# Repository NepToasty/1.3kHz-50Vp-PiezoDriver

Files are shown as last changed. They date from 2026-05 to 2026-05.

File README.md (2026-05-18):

# 1.3kHz-50Vp-PiezoDriver
1.3kHz 50Vp PiezoDriver

PiezoPCB1
PiezoPCB2

## Safety Warning and Disclaimer

This project is an experimental open-source hardware design. It can generate and/or expose voltages greater than 30 VAC, including potentially hazardous voltages. Contact with energized parts may cause electric shock, burns, equipment damage, fire, injury, or death.

This design is provided for informational, educational, and experimental use only. It is not a certified product, not safety-approved, and not intended for use in medical, life-support, safety-critical, automotive, industrial control, or other applications where failure could cause injury, death, property damage, or regulatory non-compliance.

Anyone who builds, modifies, tests, powers, or uses this design does so entirely at their own risk. The user is solely responsible for verifying the design, selecting suitable components, following applicable electrical safety practices, using appropriate insulation, fusing, enclosures, creepage/clearance distances, personal protective equipment, and complying with all applicable laws, standards, and regulations.

The authors, contributors, and copyright holders make no warranties or guarantees of any kind, express or implied, including but not limited to correctness, safety, fitness for a particular purpose, reliability, regulatory compliance, or suitability for any application.

To the fullest extent permitted by law, the authors, contributors, and copyright holders shall not be liable for any claim, damage, injury, loss, expense, or other liability arising from or related to the use, misuse, construction, modification, testing, or distribution of this project or any device based on it.

Do not build or operate this project unless you understand the risks of working with hazardous voltages.

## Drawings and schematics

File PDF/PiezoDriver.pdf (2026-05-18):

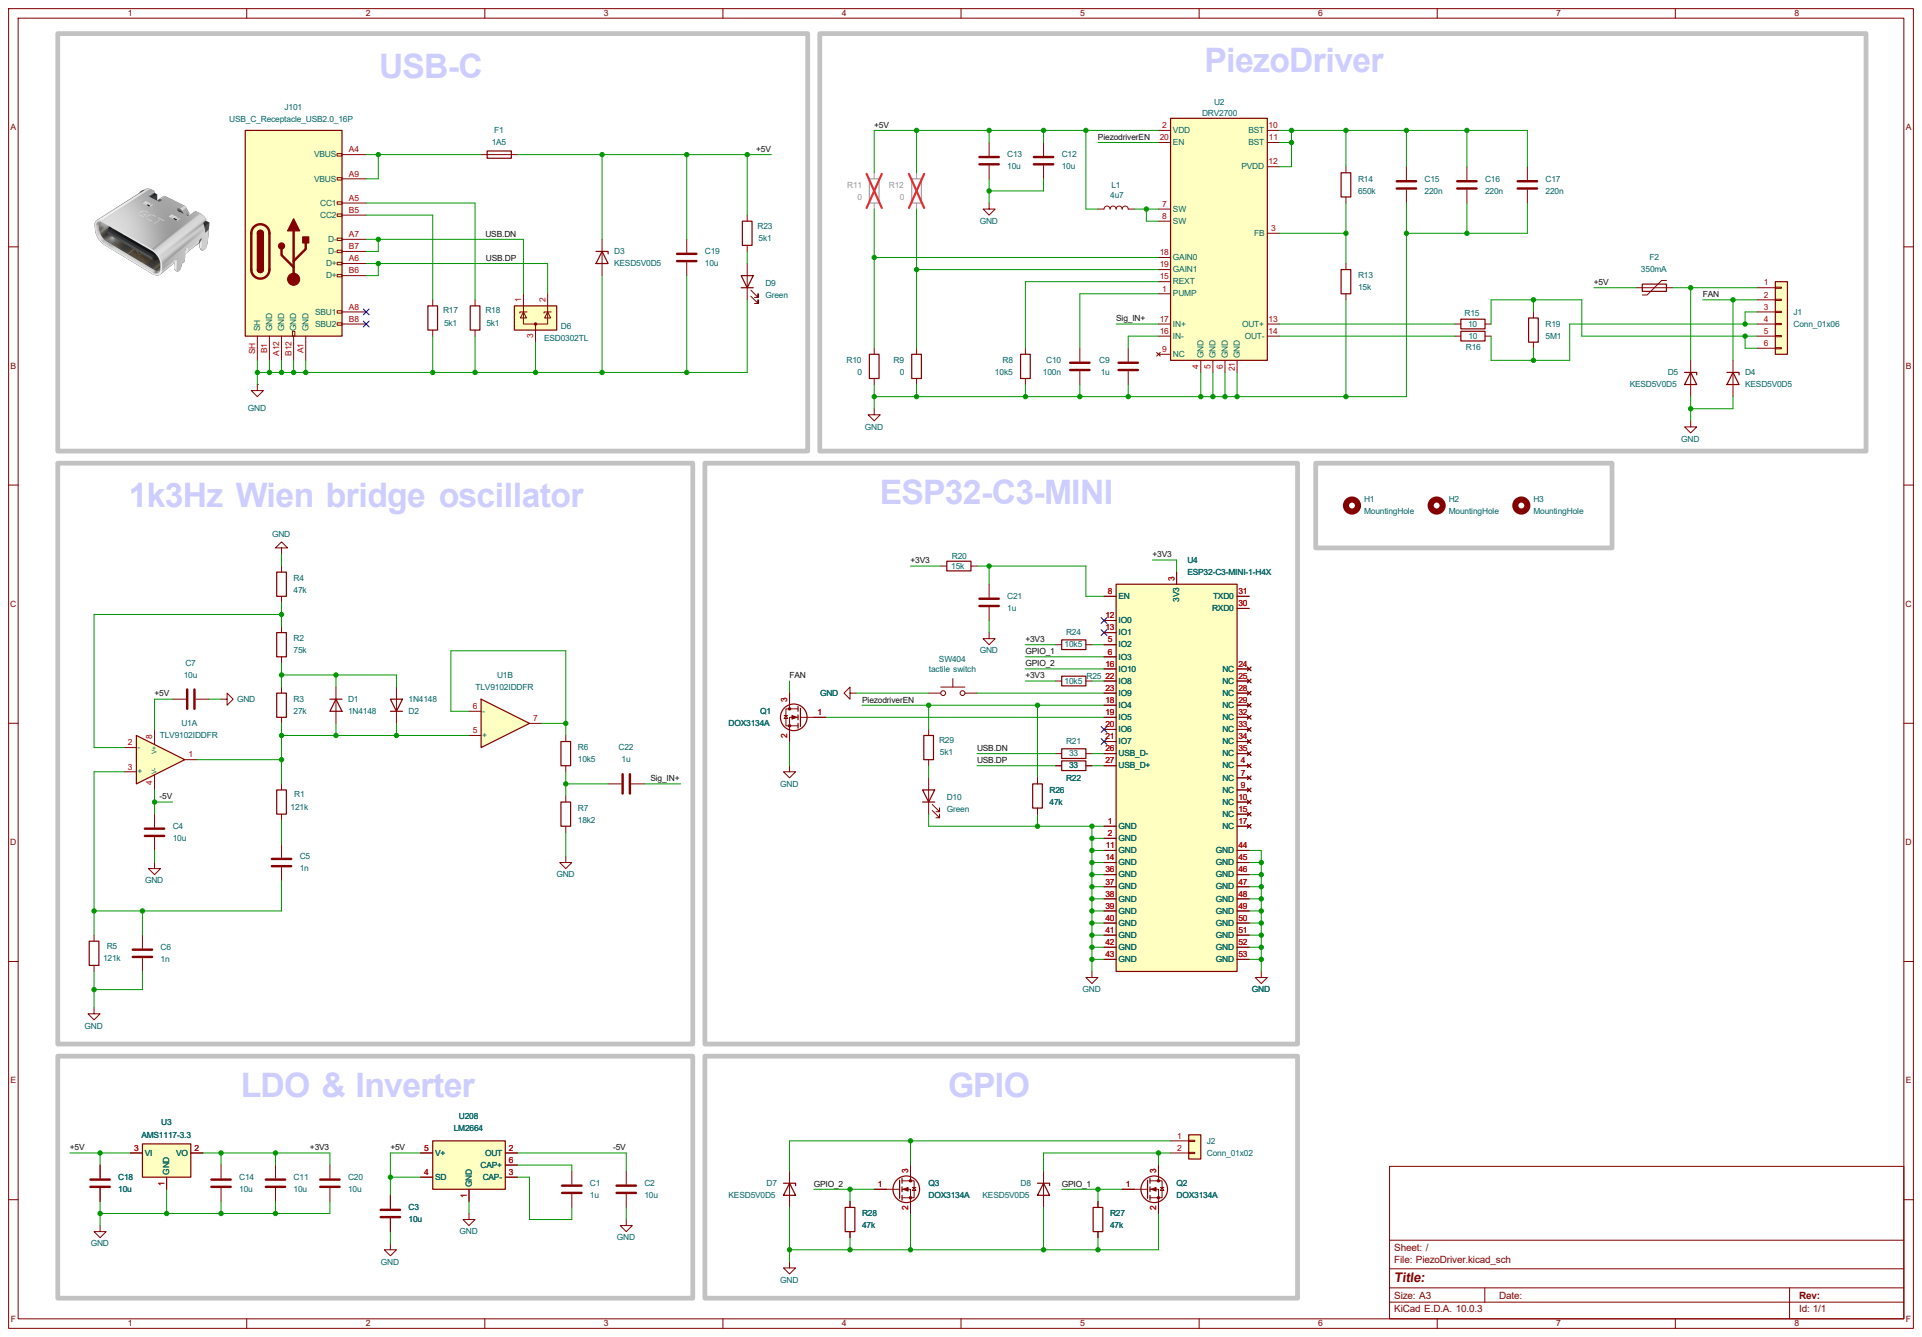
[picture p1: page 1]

6 SW 7 SW 8 NC 9 BST 10 BST 11 PVDD 12 OUT+ 13 OUT- 14 REXT 15

1 OUT 2 CAP- 3 SD 4 V+ 5 CAP+ 6 U208
LM2664 GND

1 OUT 2 CAP- 3 SD 4 V+ 5 CAP+ 6

Id: 1/1 Title: File: PiezoDriver.kicad_sch Sheet: /

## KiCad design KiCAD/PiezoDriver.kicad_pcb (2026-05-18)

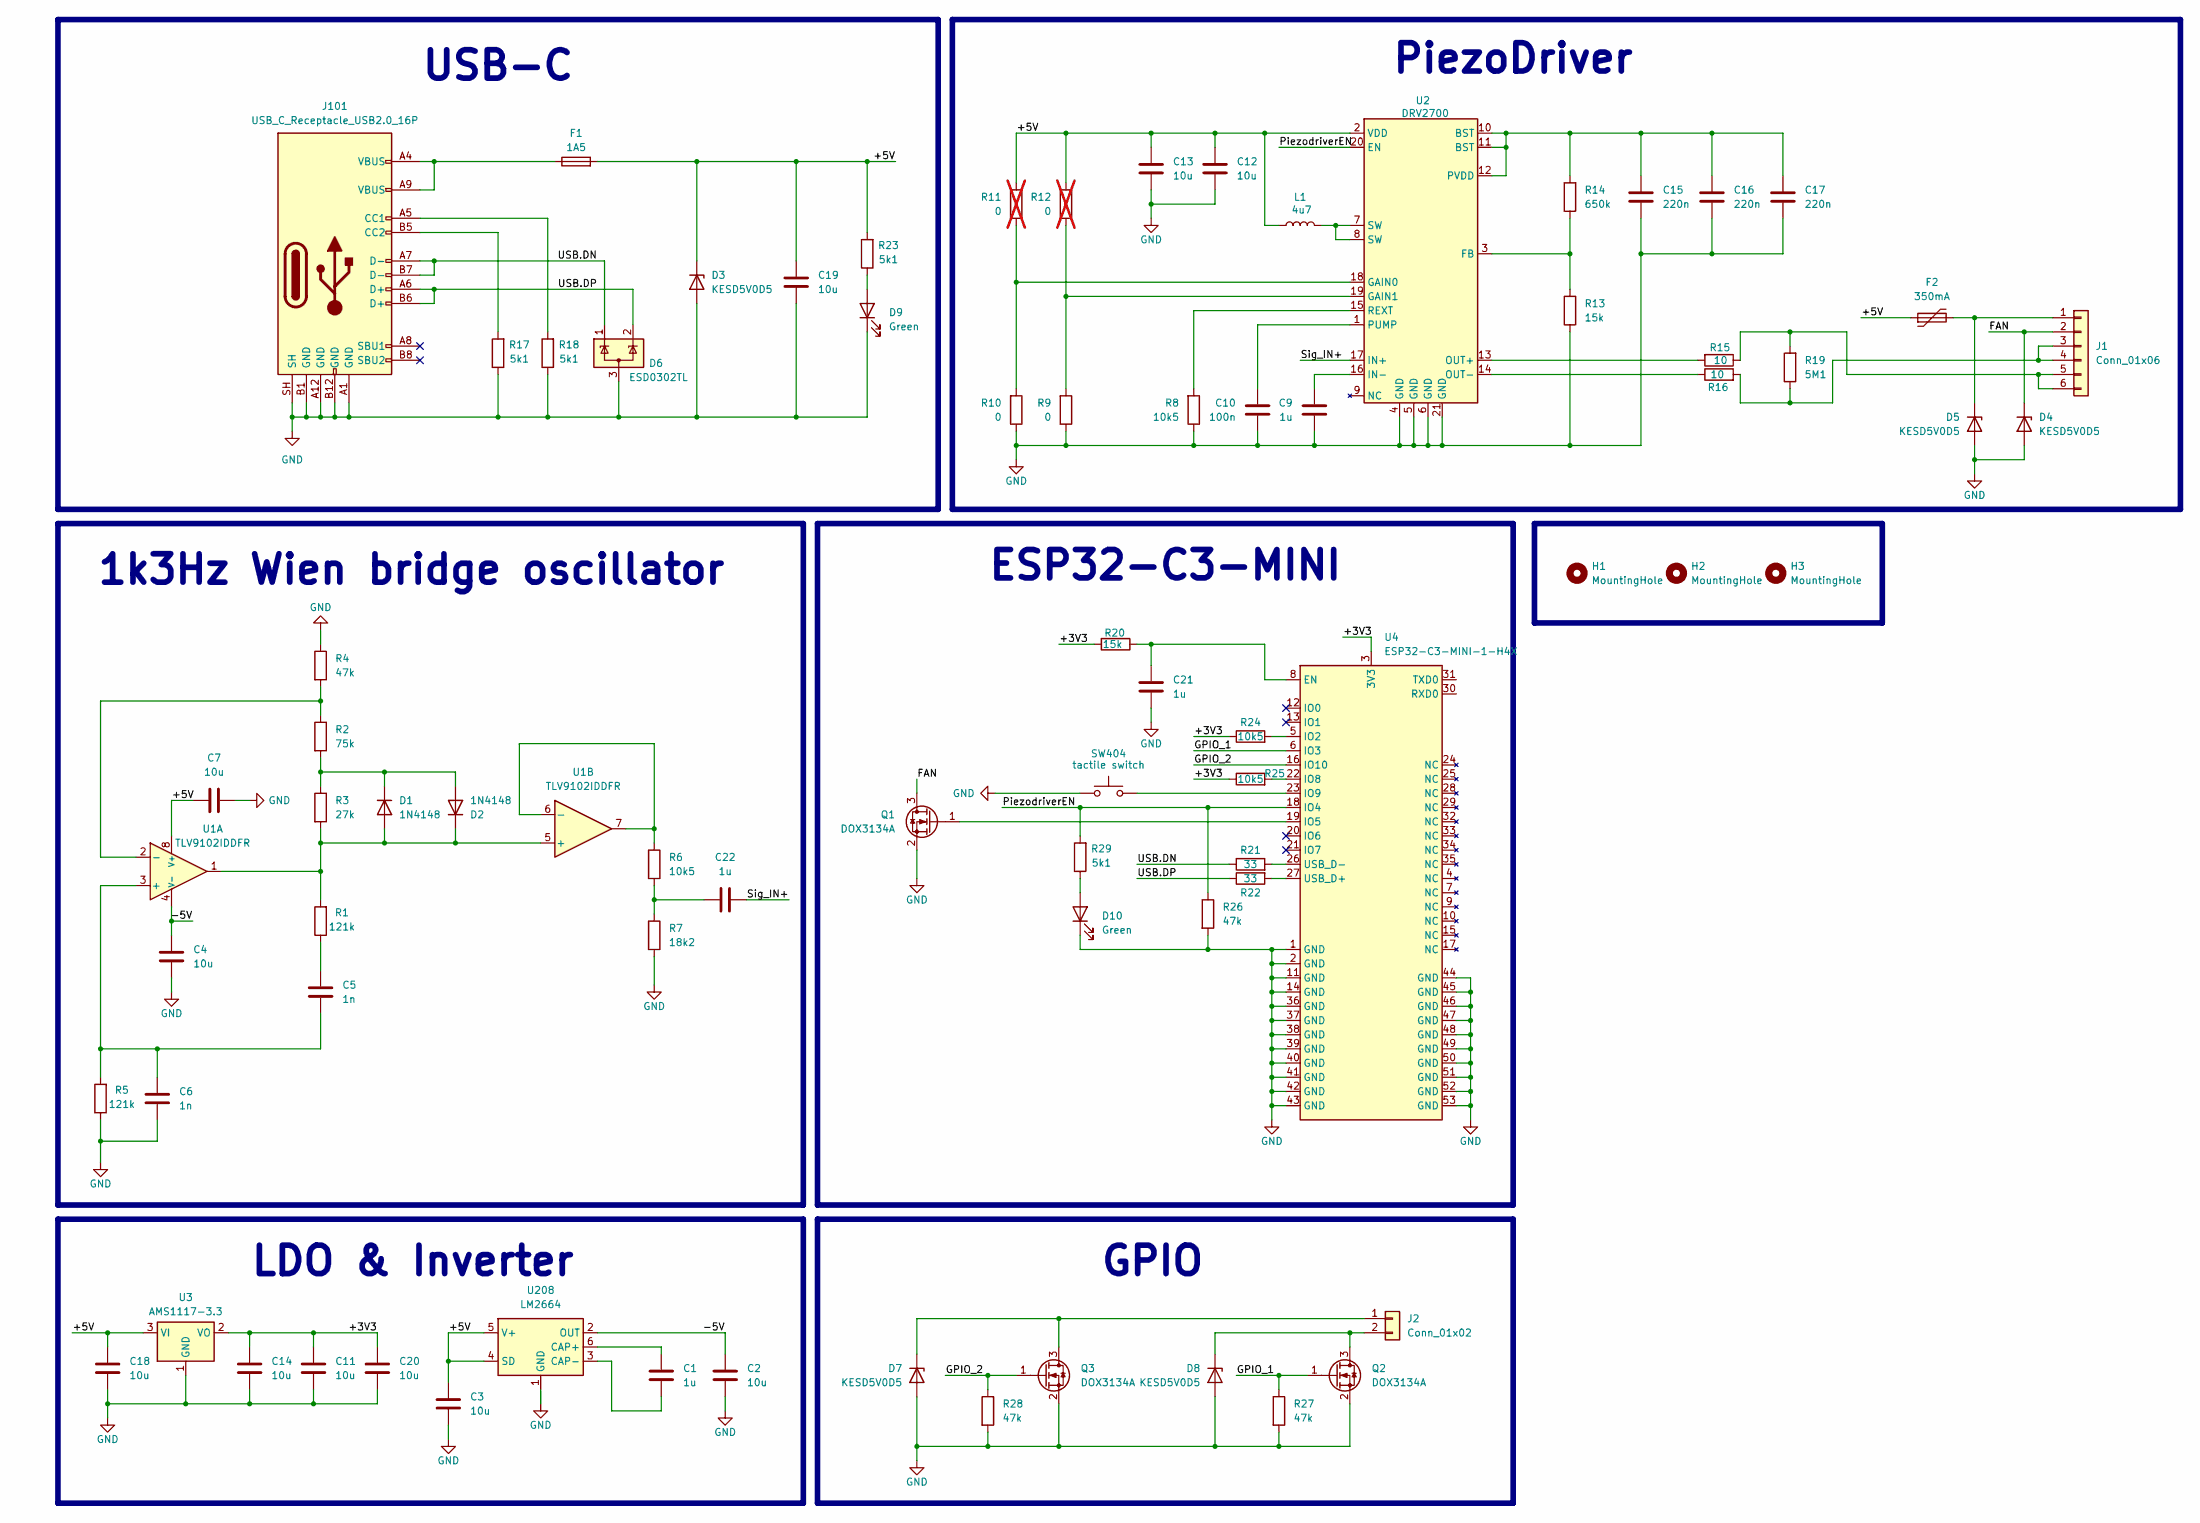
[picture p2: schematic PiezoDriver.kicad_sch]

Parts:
C1, C9, C21, C22: 1u; C_0603_1608Metric; LCSC C5199872
C2, C3, C4, C7, C11, C12, C13, C14, C18, C19, C20: 10u; C_0603_1608Metric; LCSC C6119842
C5, C6: 1n; C_0402_1005Metric; LCSC C76947
C10: 100n; C_0402_1005Metric; LCSC C77020
C15, C16, C17: 220n; C_1206_3216Metric; LCSC C880778
D1, D2: 1N4148; D_SOD-323; LCSC C60580
D3, D4, D5, D7, D8: KESD5V0D5; D_SOD-523; LCSC C2892517
D6: ESD0302TL; SOT-23; LCSC C502588
D9: Green; LED_0603_1608Metric; LCSC C52675989
D10: Green; LED_0603_1608Metric; LCSC C51933298
F1: 1A5; Fuse_0603_1608Metric; LCSC C52988544
F2: 350mA; Fuse_0603_1608Metric; LCSC C7501938
H1, H2, H3: MountingHole; MountingHole_2.2mm_M2_DIN965
J1: Conn_01x06; PinHeader_1x06_P2.54mm_Vertical
J2: Conn_01x02; PinHeader_1x02_P2.54mm_Vertical
J101: USB_C_Receptacle_USB2.0_16P; USB_C_Receptacle_G-Switch_GT-USB-7010ASV; MPN HYCW638-USBC16-650B; LCSC C53185061
L1: 4u7; L_Vishay_IFSC-1515AH_4x4x1.8mm; LCSC C92961
Q1, Q2, Q3: DOX3134A; SOT-323_SC-70; LCSC C54349756
R1, R5: 121k; R_0402_1005Metric; LCSC C11693
R2: 75k; R_0402_1005Metric; LCSC C2982949
R3: 27k; R_0402_1005Metric; LCSC C25551
R4, R26, R27, R28: 47k; R_0402_1005Metric; LCSC C2759770
R6, R8, R24, R25: 10k5; R_0402_1005Metric; LCSC C171695
R7: 18k2; R_0402_1005Metric; LCSC C25859
R9, R10: 0; R_0402_1005Metric; LCSC C163804
R11, R12: 0; R_0402_1005Metric; LCSC C163804; not fitted
R13, R20: 15k; R_0402_1005Metric; LCSC C25539
R14: 650k; R_0805_2012Metric; LCSC C137500
R15, R16: 10; R_0805_2012Metric; LCSC C25278
R17, R18, R23, R29: 5k1; R_0402_1005Metric; LCSC C25905
R19: 5M1; R_0805_2012Metric; LCSC C26118
R21, R22: 33; R_0402_1005Metric; LCSC C168263
SW404: tactile switch; SW_Push_SPST_NO_Alps_SKRK; MPN B3U-1000P; LCSC Part C720477
U1: TLV9102IDDFR; SOT-23-8; LCSC C4366877
U2: DRV2700; Texas_RGP0020D_VQFN-20-1EP_4x4mm_P0.5mm_EP2.7x2.7mm; LCSC C2150456
U3: AMS1117-3.3; SOT-89-3; LCSC C50313802
U4: ESP32-C3-MINI-1-H4X; ESP32-C6-MINI-1; LCSC C41349510
U208: LM2664; SOT-23-6; MPN LM2664M6X/NOPB; Mouser Nr. 926-LM2664M6X/NOPB

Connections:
/+3V3: C11.1, C14.1, C20.1, R20.2, R24.1, R25.1, U3.2 (VO), U4.3 (3V3)
/+5V: C3.1, C7.1, C12.2, C13.2, C18.1, C19.2, D3.1 (K), F1.2, F2.1, L1.1, R11.2, R12.2, R23.2, U1.8 (V+), U2.2 (VDD), U3.3 (VI), U208.4 (SD), U208.5 (V+)
/-5V: C2.1, C4.1, U1.4 (V-), U208.2 (OUT)
/FAN: D4.1 (K), J1.2, Q1.3 (D)
/GPIO_1: Q2.1 (G), R27.1, U4.6 (IO3)
/GPIO_2: Q3.1 (G), R28.1, U4.16 (IO10)
/PiezodriverEN: R26.1, R29.2, U2.20 (EN), U4.18 (IO4)
/Sig_IN+: C22.2, U2.17 (IN+)
/USB.DN: D6.1 (K), J101.A7 (D-), J101.B7 (D-), R21.1
/USB.DP: D6.2 (K), J101.A6 (D+), J101.B6 (D+), R22.1
GND: C2.2, C3.2, C4.2, C6.2, C7.2, C9.1, C10.2, C11.2, C12.1, C13.1, C14.2, C15.1, C16.1, C17.1, C18.2, C19.1, C20.2, C21.2, D3.2 (A), D4.2 (A), D5.2 (A), D6.3 (A), D7.2 (A), D8.2 (A), D9.1 (K), D10.1 (K), J101.A1 (GND), J101.A12 (GND), J101.B1 (GND), J101.B12 (GND), J101.SH, Q1.2 (S), Q2.2 (S), Q3.2 (S), R4.1, R5.1, R7.2, R8.1, R9.1, R10.1, R13.1, R17.1, R18.1, R26.2, R27.2, R28.2, SW404.1, U2.4 (GND), U2.5 (GND), U2.6 (GND), U2.21 (GND), U3.1 (GND), U4.1 (GND), U4.2 (GND), U4.11 (GND), U4.14 (GND), U4.36 (GND), U4.37 (GND), U4.38 (GND), U4.39 (GND), U4.40 (GND), U4.41 (GND), U4.42 (GND), U4.43 (GND), U4.44 (GND), U4.45 (GND), U4.46 (GND), U4.47 (GND), U4.48 (GND), U4.49 (GND), U4.50 (GND), U4.51 (GND), U4.52 (GND), U4.53 (GND), U208.1 (GND)
unnamed: C5.1, R1.1
unnamed: C22.1, R6.2, R7.1
unnamed: D1.2 (A), D2.1 (K), R1.2, R3.2, U1.1, U1.5 (+)
unnamed: D1.1 (K), D2.2 (A), R2.2, R3.1
unnamed: D5.1 (K), F2.2, J1.1
unnamed: D7.1 (K), J2.1, Q3.3 (D)
unnamed: D8.1 (K), J2.2, Q2.3 (D)
unnamed: D9.2 (A), R23.1
unnamed: D10.2 (A), R29.1
unnamed: F1.1, J101.A4 (VBUS), J101.A9 (VBUS), J101.B4 (VBUS), J101.B9 (VBUS)
unnamed: J1.3, J1.4, R16.2, R19.1
unnamed: J1.5, J1.6, R15.1, R19.2
unnamed: J101.A5 (CC1), R18.2
unnamed: J101.B5 (CC2), R17.2
unnamed: L1.2, U2.7 (SW), U2.8 (SW)
unnamed: Q1.1 (G), U4.19 (IO5)
unnamed: C5.2, C6.1, R5.2, U1.3 (+)
unnamed: R2.1, R4.2, U1.2 (-)
unnamed: R6.1, U1.6 (-), U1.7
unnamed: R13.2, R14.1, U2.3 (FB)
unnamed: R10.2, R11.1, U2.18 (GAIN0)
unnamed: R9.2, R12.1, U2.19 (GAIN1)
unnamed: C9.2, U2.16 (IN-)
unnamed: R15.2, U2.13 (OUT+)
unnamed: R16.1, U2.14 (OUT-)
unnamed: C10.1, U2.1 (PUMP)
unnamed: C15.2, C16.2, C17.2, R14.2, U2.10 (BST), U2.11 (BST), U2.12 (PVDD)
unnamed: R8.2, U2.15 (REXT)
unnamed: C21.1, R20.1, U4.8 (EN)
unnamed: R24.2, U4.5 (IO2)
unnamed: R25.2, U4.22 (IO8)
unnamed: SW404.2, U4.23 (IO9)
unnamed: R22.2, U4.27 (USB_D+)
unnamed: R21.2, U4.26 (USB_D-)
unnamed: C1.1, U208.6 (CAP+)
unnamed: C1.2, U208.3 (CAP-)

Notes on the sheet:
USB-C
LDO & Inverter
PiezoDriver
ESP32-C3-MINI
1k3Hz Wien bridge oscillator
GPIO

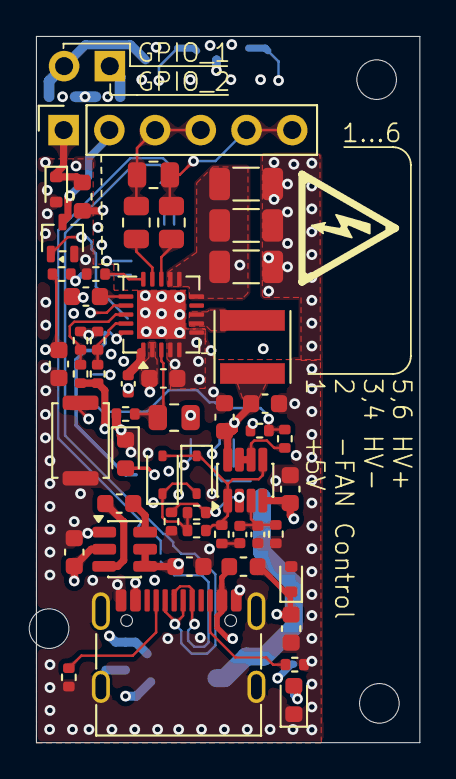
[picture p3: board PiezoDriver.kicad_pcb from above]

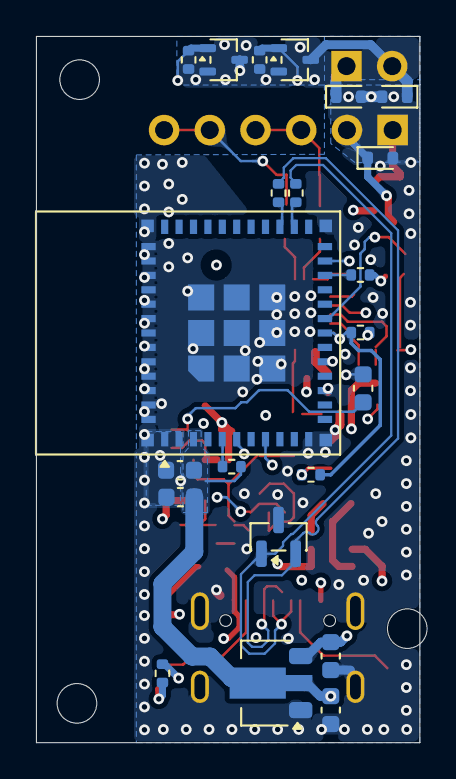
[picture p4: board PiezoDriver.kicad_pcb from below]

Board: 6 copper layers, 21.3 x 39.2 mm, 78 parts (22 on the bottom side), 47 nets.
